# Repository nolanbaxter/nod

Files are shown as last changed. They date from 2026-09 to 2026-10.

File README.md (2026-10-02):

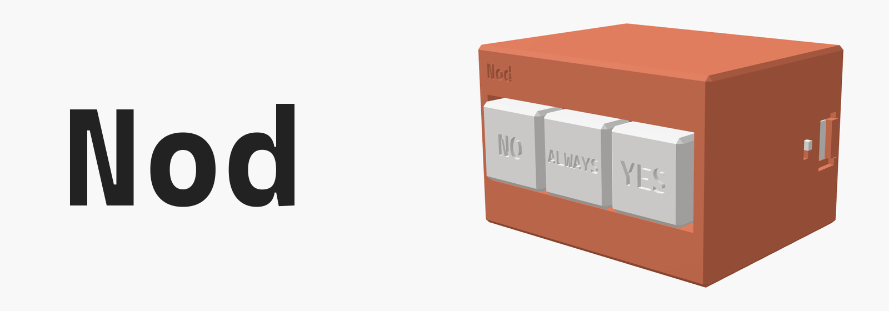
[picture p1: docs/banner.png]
Nod


A three-key desk pad for answering coding-agent permission prompts: **No**, **Always**, **Yes**.
Built for [Claude Code](https://docs.anthropic.com/en/docs/claude-code)'s numbered prompts, but
the keys are one line to remap. Works over USB-C or Bluetooth, runs on a small LiPo, and sleeps
when you're not using it.

> **Status:** built and working. The first one is the [Clawd variant](#clawd-variant), tested on
> real hardware over USB and Bluetooth in both the desktop app and the terminal. The plain Nod
> box shares its plate, keycaps and insides, but its current body and lid haven't been printed yet.

Not affiliated with or endorsed by Anthropic.

## Keys

| Key (left to right) | Sends | In a Claude desktop app prompt |
|---|---|---|
| NO | `Esc` | Deny |
| ALWAYS | `Ctrl+Shift+Enter` | Always allow |
| YES | `Ctrl+Enter` | Allow once |

These are the shortcuts the Claude desktop app shows on its prompt buttons, tested on the real
device. The number keys shown next to the buttons are positional and change from prompt to prompt,
so Nod doesn't use them. Leave the cursor in the message box, not on the prompt card.

Some prompts (multi-step or piped commands) have only Deny and Allow once. There, ALWAYS does
nothing and YES allows once. Text you've typed in the message box isn't sent when YES approves a
prompt.

### Terminal keymap

Claude Code in a terminal numbers its options instead: 1 Yes, 2 don't ask again, 3 No (Yes/No
prompts have only 1 and 2). **Hold NO + ALWAYS for 3 s** to switch between the desktop and
terminal keymaps. The LED gives one long blink for desktop, two for terminal, and Nod remembers the
choice through sleep and power-off.

| Key | Sends | 3-option prompt | Yes/No prompt |
|---|---|---|---|
| NO | `Esc` | No | No |
| ALWAYS | `2` | Yes, don't ask again | No |
| YES | `1` | Yes | Yes |

Every key fires once, 80 ms after it's pressed (the wait tells a single press from a two-key hold). To remap, edit `CODE` (both keymaps) in [`src/main.cpp`](src/main.cpp) and the
`labels` in [`cad/case.scad`](cad/case.scad).

## How it behaves

- **USB or Bluetooth, automatically.** Plugged into a computer, it's a USB keyboard. Unplugged,
  or on a charger, it's a Bluetooth keyboard named **Nod**. Each press goes out one way only.
- **Sleep.** On battery, it deep-sleeps after 2 minutes without a press. Any key wakes it; that
  press is sent once Bluetooth reconnects (1â€“3 s), or dropped if that takes over 5 s, so a stale
  "Yes" never lands on a newer prompt.
- **Pairing.** It's discoverable as **Nod** whenever nothing is connected. To move it to another
  computer, hold **NO + YES** together for 3 s: it forgets every paired computer and waits for a
  new one. Remove Nod from the old computer's Bluetooth list too, or it keeps trying to reconnect.
  (Keys pressed together never send, so this can't approve a prompt by accident.)
- **LED** (the programmable one, next to the USB port):
  - quick flash: a key was sent
  - fast blink: pairing
  - short blink every second: waiting for a connection
  - short blink every 4 s: battery low (needs two resistors; see `BAT_PIN` in `src/main.cpp`)
- **Charging.** The XIAO's own red LED is on while the battery charges and goes out when it's full.
  The power switch has to be on.
- **Power switch** on the side cuts the battery. It has to be **on** for the battery to charge.

## Parts (one build)

| Part | Notes |
|---|---|
| Seeed Studio XIAO ESP32-S3 | The plain one, not Sense or Plus |
| 2.4 GHz FPC antenna, U.FL / IPEX-1 | The XIAO has no onboard antenna. ~50 Ã— 14 mm fits the case |
| 3 Ã— MX-style switches | 3-pin or 5-pin, plate-mount. Any feel |
| 502030 LiPo, 3.7 V ~250 mAh, **with protection circuit** | Stands on edge inside |
| SS12D00**G3** mini slide switch | Power. G3 = 3 mm slider; the case has a finger pocket sized for it. Not SS12D10/SS12F44 "5 mm knob" parts: their bodies are bigger |
| 8 Ã— 6 Ã— 2 mm disc magnets | Hold the lid on |
| 28â€“30 AWG silicone wire, heat-shrink, Kapton tape, gel superglue | |
| PLA | Case, plate, keycaps; a second colour for labels is optional |

## Wiring

Wiring diagram

Keys go to **D0 / D1 / D3** (NO / ALWAYS / YES), their other pins all to **GND**. No resistors:
the firmware uses the chip's internal pull-ups. The power switch sits in the battery's **+**
lead. Solder the battery last.

## Case

Parametric [OpenSCAD](https://openscad.org) model: [`cad/case.scad`](cad/case.scad).
Ready-to-print STLs are in `cad/stl/bevel/` (1 mm 45Â° edges) and `cad/stl/square/`.

| File | Print orientation |
|---|---|
| `body.stl` | As exported: top face down. Designed to print without supports (not yet test-printed) |
| `lid.stl` | Flat side down |
| `plate.stl` | Flat. Print this first to test how your switches clip in |
| `keycaps.stl` | Top face down. Labels are engraved; to fill them in a second colour, load `labels.stl` with it as one object |

The switch plate is a separate part so it prints perfectly flat; it drops into the key well and
gets a dab of glue. Glue the magnets in pairs: stack each pair first and mark the touching faces,
so the lid attracts instead of repelling.

Keycap labels use [Cascadia Code](https://github.com/microsoft/cascadia-code) Bold (free). The STLs
already have it baked in; to re-export them, install the font first, or OpenSCAD silently swaps in
a default one.

Useful knobs at the top of `case.scad`: `sw_hole` (switch fit), `cross_l`/`cross_w` (keycap fit),
`cap_proud` (how far keys stick out), `chamfer` (0 for square edges), and every `measure` value.

After changing anything, run the collision check (Windows, needs OpenSCAD and `pip install trimesh`):

```powershell
powershell -File cad/check.ps1
```

The README images are rendered from the model too: `powershell -File docs/banner/make_banner.ps1`
(add `-Target clawd` for the Clawd image; also needs `pip install pillow` and Microsoft Edge).

## Clawd variant

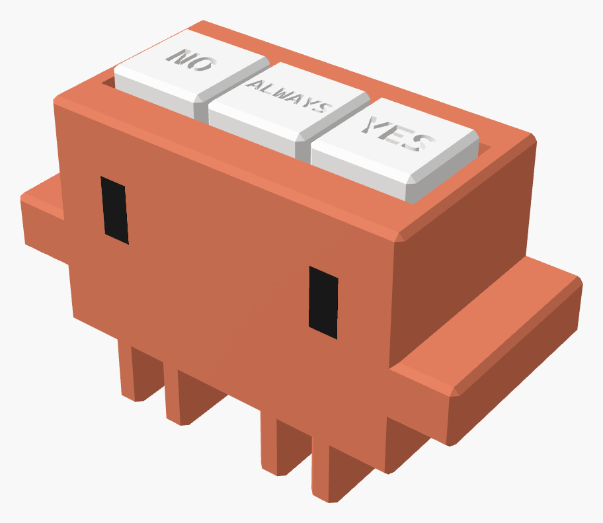
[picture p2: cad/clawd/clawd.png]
Clawd


*Unofficial, noncommercial fan-made recreation of Clawd, the Claude Code mascot. Not affiliated with, authorized, or endorsed by Anthropic.*

The same insides and keys in a Clawd-shaped body: [`cad/clawd/clawd.scad`](cad/clawd/clawd.scad)
builds on `case.scad`. The USB port, LED holes and power switch sit on the back wall, beside
each other. STLs are in `cad/clawd/stl/`; the plate and keycaps are the same as Nod's.

| File | Print orientation |
|---|---|
| `body.stl` + `eyes.stl` | As exported: top face down. Load together for black eyes. Supports under the arms |
| `lid.stl` | Standing on its legs. Supports under the plate between the legs |

The Clawd files are licensed **CC BY-NC 4.0** (noncommercial); see [`cad/clawd/LICENSE`](cad/clawd/LICENSE).

## Firmware

[PlatformIO](https://platformio.org), Arduino framework, NimBLE.

```bash
pio test -e native     # logic tests on your PC (needs gcc)
pio run -e xiao -t upload
```

If upload can't find the board, hold **BOOT** while plugging it in, then upload again.

| File | What |
|---|---|
| `src/main.cpp` | Pins, keymap, main loop, sleep |
| `src/usb_out.cpp`, `src/ble_out.cpp` | USB and Bluetooth keyboards (separate files: their headers clash) |
| `include/keys.h` | Debounce, wake-key and sleep decisions: pure logic, unit tested |

## License

Nod (firmware, case, docs): [MIT](LICENSE).
The Clawd variant in `cad/clawd/`: [CC BY-NC 4.0](cad/clawd/LICENSE), noncommercial use only.

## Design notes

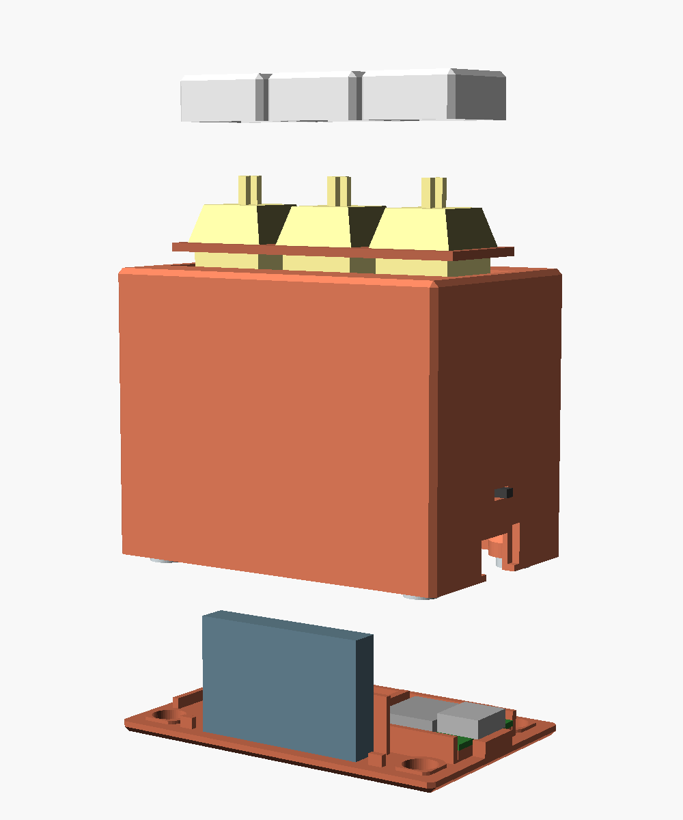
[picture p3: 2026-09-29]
cad/preview/exploded.png

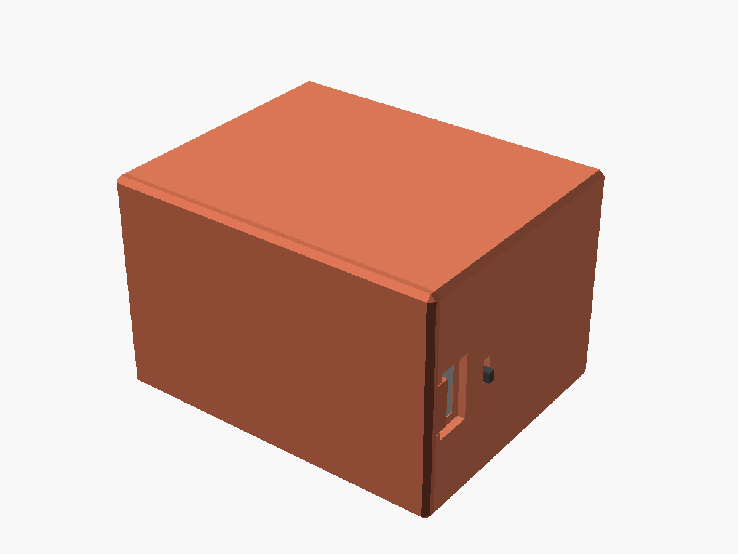
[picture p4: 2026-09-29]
cad/preview/lying.png

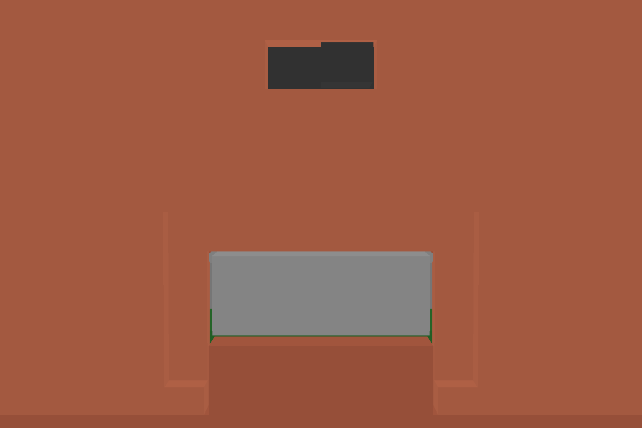
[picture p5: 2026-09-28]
cad/preview/port_closeup.png

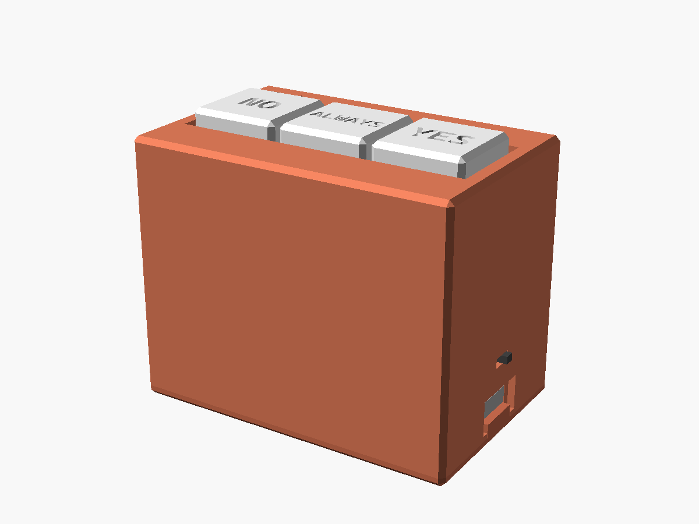
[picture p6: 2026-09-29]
cad/preview/upright.png

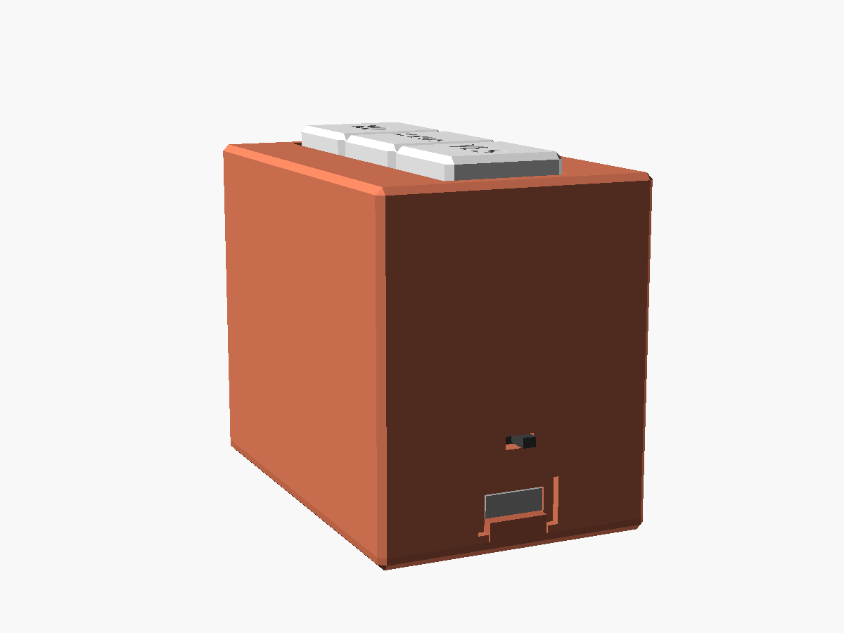
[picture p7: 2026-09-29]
cad/preview/port_side.png

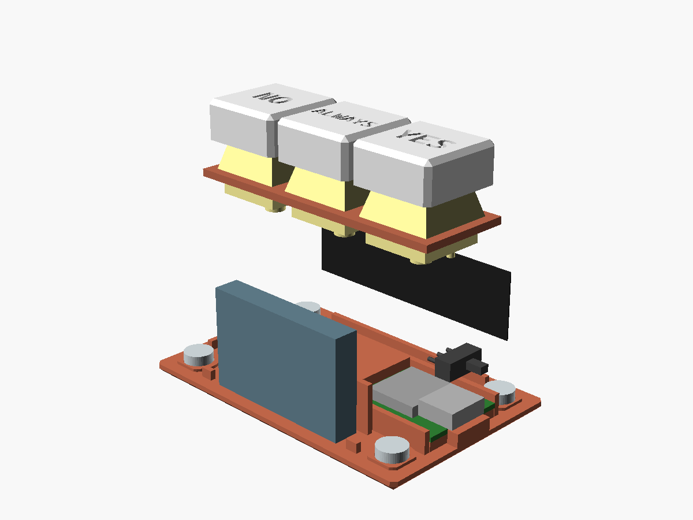
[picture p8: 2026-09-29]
cad/preview/inside.png

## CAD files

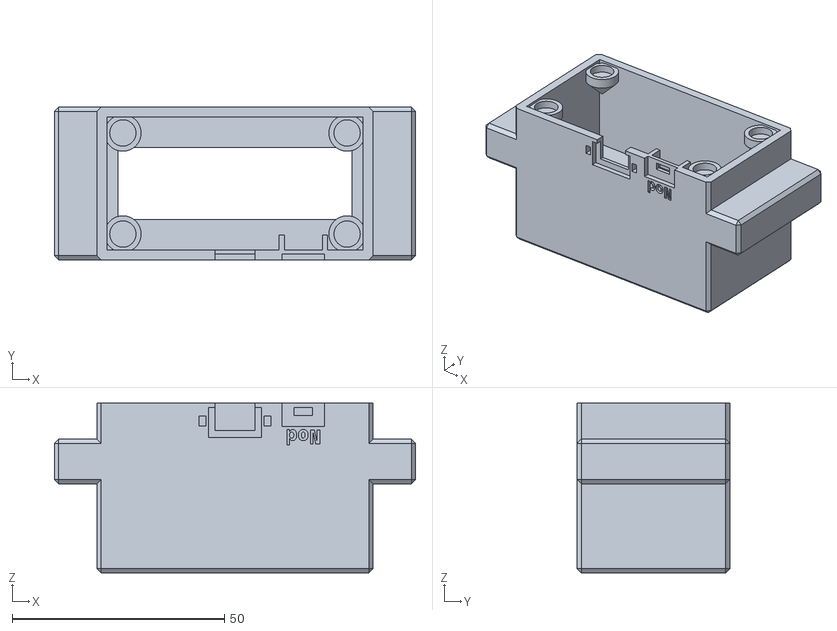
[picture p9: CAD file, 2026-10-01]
cad/clawd/stl/bevel/body.stl
85.0 x 36.0 x 40.0

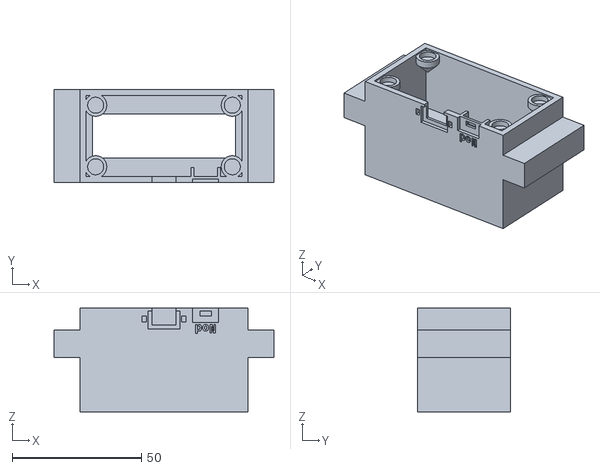
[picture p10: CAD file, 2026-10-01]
cad/clawd/stl/square/body.stl
85.0 x 36.0 x 40.0

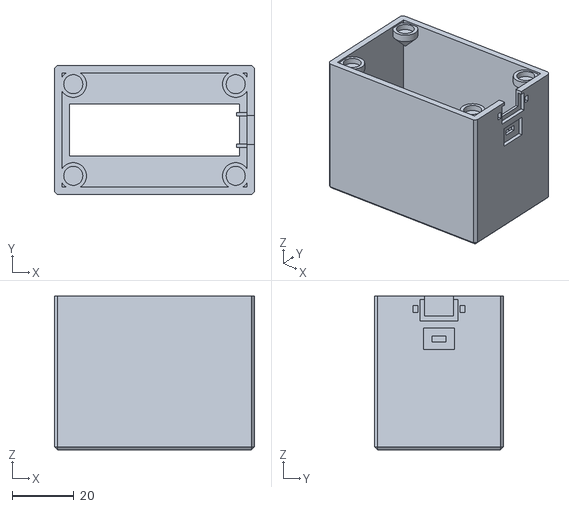
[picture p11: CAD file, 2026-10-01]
cad/stl/bevel/body.stl
65.0 x 42.0 x 50.0

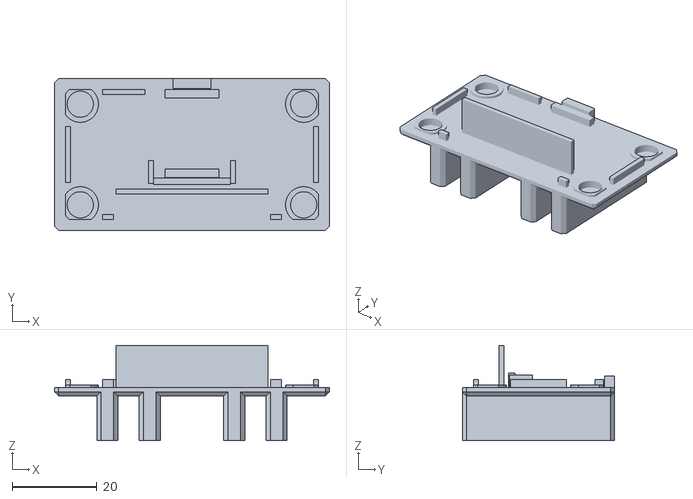
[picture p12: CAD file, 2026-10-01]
cad/clawd/stl/bevel/lid.stl
65.0 x 36.0 x 22.5

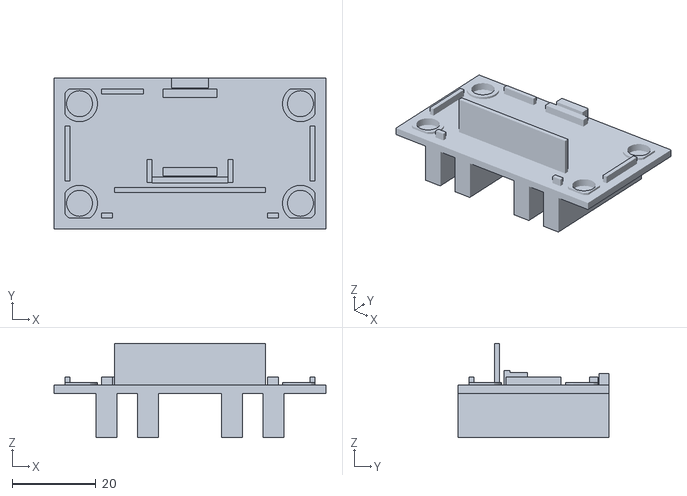
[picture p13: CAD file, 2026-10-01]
cad/clawd/stl/square/lid.stl
65.0 x 36.0 x 22.5

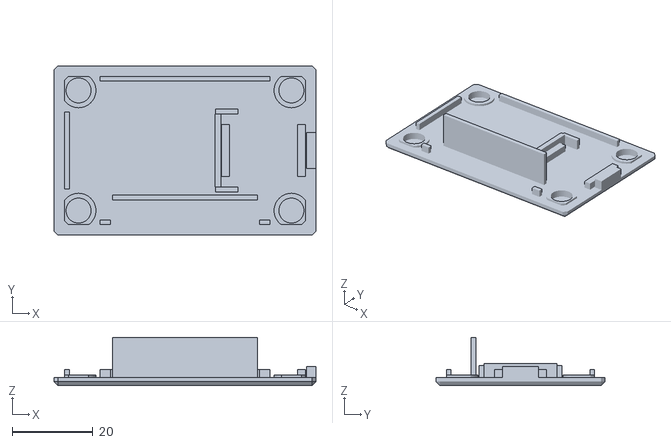
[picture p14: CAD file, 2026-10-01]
cad/stl/bevel/lid.stl
65.0 x 42.0 x 12.0

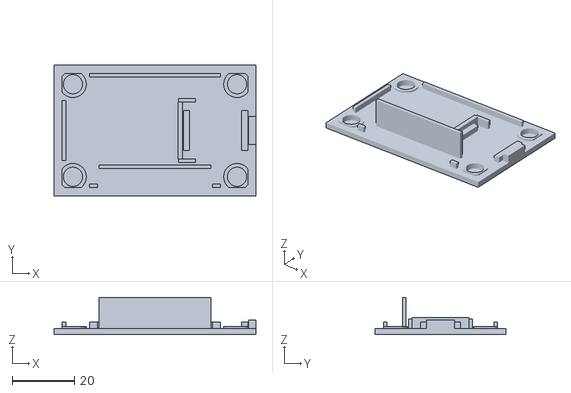
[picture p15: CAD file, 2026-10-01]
cad/stl/square/lid.stl
65.0 x 42.0 x 12.0

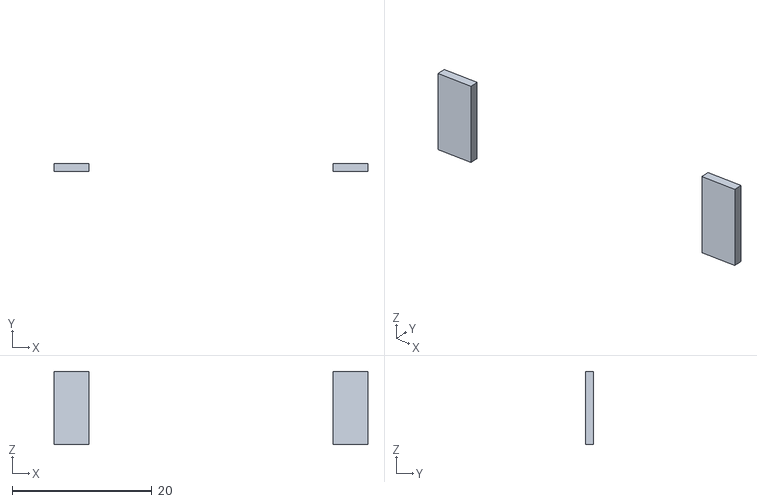
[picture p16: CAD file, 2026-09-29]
cad/clawd/stl/bevel/eyes.stl
45.0 x 1.21 x 10.5

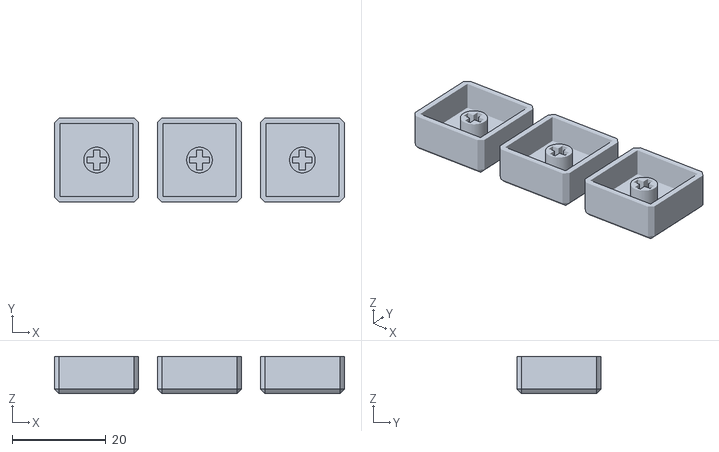
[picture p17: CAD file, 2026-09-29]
cad/stl/bevel/keycaps.stl
62.0 x 18.0 x 8.00

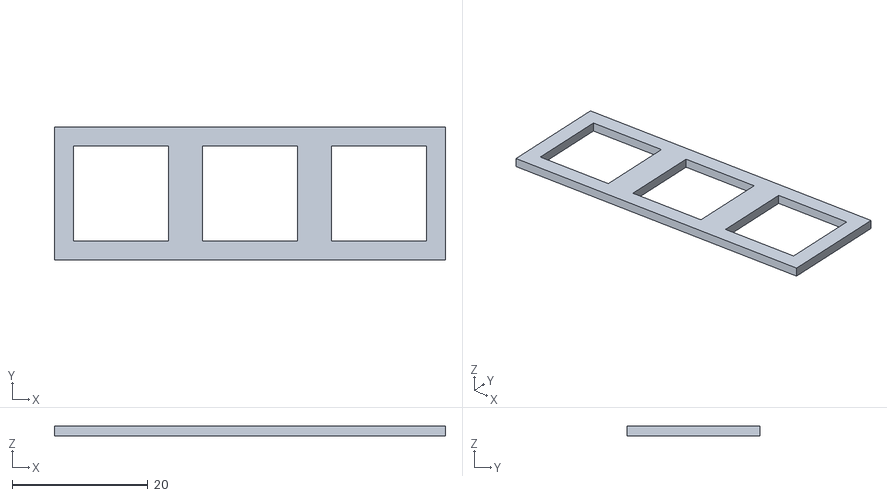
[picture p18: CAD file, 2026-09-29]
cad/stl/square/plate.stl
57.7 x 19.6 x 1.50

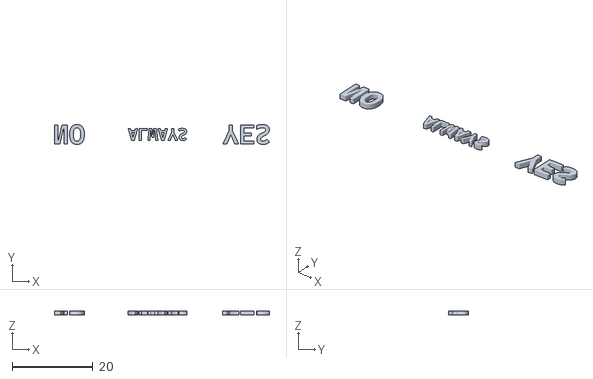
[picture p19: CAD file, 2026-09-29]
cad/stl/square/labels.stl
53.2 x 4.95 x 1.01

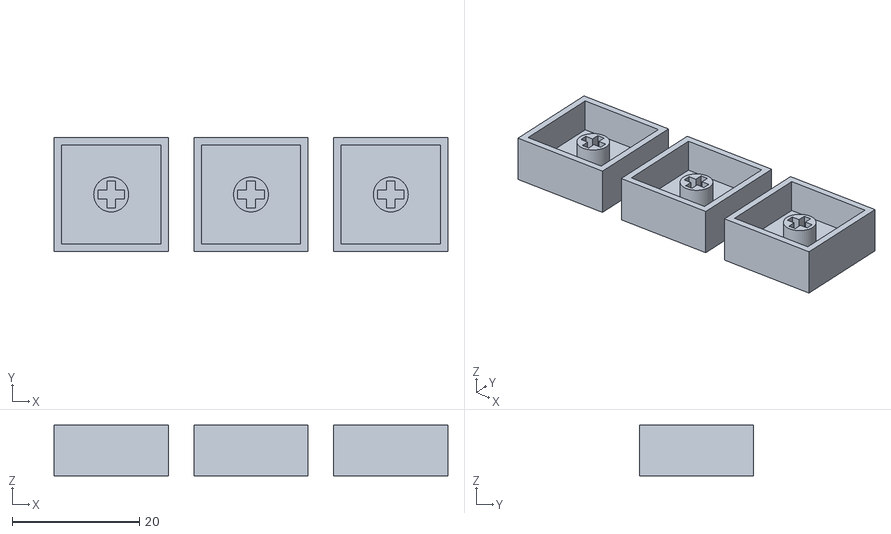
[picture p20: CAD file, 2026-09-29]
cad/stl/square/keycaps.stl
62.0 x 18.0 x 8.00

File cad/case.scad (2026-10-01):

// Nod case: a three-key box. Units mm.
// Coordinates: x centered, y=0 front face, y=depth back face, z=0 bottom of lid.
// Every "measure" value is a nominal guess until the real part is in hand.

part = "all"; // [all, body, lid, plate, keycaps, labels]

/* [Shape] */
W = 65;               // width; must fit 3 keys at 19.05 mm pitch
depth = 42;           // deep enough for the side USB port to fit between the corner magnets
H = 52;
wall = 2.4;
plate = 1.5;          // MX plate-mount thickness
lid_t = 2;
chamfer = 1;          // 45° bevel on outside edges; 0 = square; keep <= lid_t/2

/* [Switches] */
pitch = 19.05;
sw_hole = 14.0;       // tune +0.1 if switches won't clip in
cap_proud = 3;        // how far keycap tops stick out above the top face
well_gap = 1;         // gap around each keycap inside the key well
ledge = 1.5;          // lip the separate plate rests on
rim = 2;              // thickness of that lip

/* [XIAO ESP32-S3] measure */
xiao_l = 21;          // USB end against the right wall
xiao_w = 17.8;
pcb_t = 1.0;
xiao_lift = 2;        // clearance under board for battery-pad wires
usb_w = 8.94;         // receptacle
usb_h = 3.26;
usb_over = 1.0;       // how far the receptacle sticks past the PCB edge
usb_zc = 2.6;         // receptacle center above PCB bottom
plug_w = 12.5;        // cable overmold
plug_h = 7;

/* [Battery] 502030 LiPo, listed 20.5 x 32 x 5.3 */
bat_l = 32;
bat_t = 5.3;
bat_slack = 1;        // LiPos swell

/* [Power switch] SS12D00-G3 mini slide switch (3 mm slider), measure */
sw_l = 8.6;           // body length (slide direction)
sw_w = 3.6;
sw_h = 3.5;
knob_l = 2.0;         // slider cross-section
knob_w = 1.5;
knob_travel = 2.0;
knob_h = 3;           // slider length past the switch face: G3 = 3 mm
sw_pocket = [10, 7];  // finger pocket around the slot on the outside (along the wall, height)
sw_pocket_wall = 1.0; // wall left at the pocket floor, so the 3 mm slider stands 2 mm proud

/* [Magnets] 6 x 2 mm discs */
mag_d = 6;            // diameter
mag_h = 2;            // thickness
mag_fit = 0.2;        // pocket clearance on diameter; glue them in
lip_h = 2;            // lid lip inside the walls: magnets hold vertically, the lip stops sliding

/* [Antenna] 2.4 GHz FPC, U.FL/IPEX-1, 50 x 14 */
ant_l = 50;
ant_w = 14;
ant_z = 12.2;         // bottom edge height on the back wall

/* [Keycaps] */
cap = 18;
cap_wall = 1.2;
cap_top = 2.4;
cap_skirt = 5.6;      // skirt bottom to socket bottom
cap_rest = 6.0;       // skirt bottom height above the plate at rest (MX stem top is 11.6 above plate)
stem_d = 5.5;
cross_l = 4.2;        // tune for stem fit
cross_w = 1.35;
cross_depth = 4;
labels = ["NO", "ALWAYS", "YES"];   // left to right, matches src/main.cpp CODE[]
label_size = [5, 3.1, 5];
label_font = "Cascadia Code:style=Bold";   // free, github.com/microsoft/cascadia-code; OpenSCAD silently falls back if missing
label_depth = 1.0;   // engraving depth for key labels and the logo

/* [Logo] engraved on the top face, behind the keys */
logo = "Nod";
logo_size = 3.5;
logo_side = "left";   // [left, right]

/* [Fit] */
tol = 0.2;

$fn = 48;
cap_h = cap_skirt + cap_top;
port_z = lid_t + xiao_lift + usb_zc;          // USB center height
cav = [W - 2*wall, depth - 2*wall];           // interior footprint
mag_pd = mag_d + mag_fit;                     // pocket diameter
boss_d = mag_pd + 2.4;
mag_off = mag_pd/2 + tol + 0.4;               // magnet center from inner wall faces
mag_z = max(lid_t, mag_h + 0.6);              // where magnet faces meet
boss_top = mag_z + mag_h + 0.6 + boss_d/2;    // tip of the 45° cone above each body boss
mag_xy = [for (sx = [-1, 1], y = [wall + mag_off, depth - wall - mag_off])
          [sx * (W/2 - wall - mag_off), y]];
led_z0 = port_z + plug_h/2 + 0.5;             // clear band above the plug recess (Nod's switch and the antenna sit above it)
led_top = led_z0 + 1.5;
// The XIAO's two LEDs sit either side of the USB-C, ~40% of the way from the port edge to the board edge
// (measured on the real board). Their holes go just outside the plug recess so a plugged-in cable
// doesn't cover the charge LED.
led_hole = [1.6, 2.4];                         // width, height; bottom at the board's top face
led_hole_x = plug_w/2 + 0.6 + led_hole.x/2;    // centre, either side of the port
well = [2*pitch + cap + 2*well_gap, cap + 2*well_gap];   // key well footprint, centered on the top
plate_top = H - (cap_rest + cap_h - cap_proud);          // switch plate sits at the bottom of the well
ceil_z = plate_top - plate - rim;                        // underside of the solid top block

// Port cluster (USB, LED holes, power switch, XIAO pocket), modelled in a local frame:
// x along the wall, y = 0 at its outer face and negative going inside.
// Nod: right side wall, switch above the port (that wall is too short for both side by side).
xl0 = -wall - xiao_l;                          // PCB inner edge; the USB edge butts the wall
port_side = "right";                           // right | back
sw_lx = 0;                                     // power switch position along the port wall
sw_z = led_top + 2 + sw_w/2;
rib_z0 = sw_z - sw_w/2 - 1;                    // bottom of the switch guide ribs
module at_port() {
  if (port_side == "back") translate([0, depth, 0]) children();
  else translate([W/2, depth/2, 0]) rotate(-90) children();
}

// Hooks for variants built on this file (see cad/clawd/clawd.scad); empty for Nod.
lid_lift = 0;                                  // raise the exported lid (e.g. for legs)
module body_add() {}
module body_cut() {}
module lid_add() {}
module preview_add() {}

assert(port_z - plug_h/2 > lid_t, "cable overmold would hit the lid; raise xiao_lift");
assert(ant_z > led_top && ant_z + ant_w + 1 < ceil_z, "antenna overlaps the band above the port or the top block; move ant_z");
assert(well.x + 2 < W, "key well too wide for the body");
assert(ant_l + 1 < cav.x && (ant_z > boss_top || ant_l/2 + 0.5 < cav.x/2 - mag_off - boss_d/2),
       "antenna runs into a corner magnet boss");
assert(2*chamfer <= lid_t && 2*chamfer <= wall, "chamfer too big for lid/wall");

module box(p, s) translate(p) cube(s);

// box with 45° chamfers on all edges; bot/top=false leaves that face's edges square
module cbox(p, s, bot = true, top = true, c = chamfer) {
  lo = bot ? 0 : c;
  h = s.z + lo + (top ? 0 : c);
  intersection() {
    box(p, s);
    translate(p - [0, 0, lo]) hull() {
      translate([c, c, 0]) cube([s.x - 2*c, s.y - 2*c, h]);
      translate([c, 0, c]) cube([s.x - 2*c, s.y, h - 2*c]);
      translate([0, c, c]) cube([s.x, s.y - 2*c, h - 2*c]);
    }
  }
}

// logo sits in the strip between the key well and the back edge, flush with the well's left or right edge
module logo_shape() {
  right = logo_side == "right";
  translate([right ? well.x/2 : -well.x/2, depth - (depth/2 - well.y/2)/2, H - label_depth])
    linear_extrude(label_depth + 0.01)
      text(logo, size = logo_size, halign = right ? "right" : "left", valign = "center", font = label_font);
}
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

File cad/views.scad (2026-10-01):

// Extra render views. Run with -D view="port" | "lying" | "banner" | "banner_body" | "banner_accent".
include <case.scad>
part = "none";
view = "port";

if (view == "port") {  // right side: USB port, LED holes, power switch
  color("#DA7756") body();
  color("#C86A4C") lid();
  xiao_dummy();
  slide_dummy();
}
if (view == "lying") rotate([-90, 0, 0]) assembly();  // on its back
if (view == "banner") rotate([90, 0, 0]) assembly();  // on its front: keys face the camera, labels read upright
// banner colour groups, exported as real geometry (the preview renderer mangles shallow engravings)
if (view == "banner_body") rotate([90, 0, 0]) { body(); lid(); }
if (view == "banner_accent") rotate([90, 0, 0]) { keycaps_placed(); slide_dummy(); xiao_dummy(); }

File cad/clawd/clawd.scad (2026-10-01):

// Clawd style of the Nod case: the pixel mascot, with the keys on its head.
// Unofficial, noncommercial fan work, licensed CC BY-NC 4.0 (see LICENSE in this folder).
// Everything inside (XIAO pocket, magnets, key well, keycaps) comes from ../case.scad;
// this file only changes the shape and moves the port cluster to the back wall.
include <../case.scad>

/* [Clawd] */
px_w = 5;             // one pixel of the sprite; 13 px wide = the Nod width
px_h = 10.5;          // px_w * 2.1: terminal half-block aspect
eye_d = 1.2;          // eye recess depth (fill with eyes.stl in black)
depth = 36;
H = 42;               // 4 px_h tall (+ 1 px_h of legs under the lid)
port_side = "back";
sw_lx = 16.1;         // power switch beside the port, sitting on the lid
sw_z = lid_t + tol + sw_w/2;
rib_z0 = lid_t;
lid_lift = 10.5;      // legs hang below the lid
logo = "";
sink = max(2*chamfer, 0.5);   // arms/legs overlap the body so their bevels are buried

module eyes() for (c = [2, 10]) box([-W/2 + c*px_w, -0.01, 2*px_h], [px_w, eye_d + 0.01, px_h]);
module body_add() for (s = [-1, 1]) cbox([s > 0 ? W/2 - sink : -W/2 - 2*px_w, 0, px_h], [2*px_w + sink, depth, px_h]);
// "Nod" engraved on the back wall above the power switch (the space above the port is kept clear).
// rotate: text stands up on the back face and reads correctly from behind; it cuts label_depth in.
module back_logo() translate([sw_lx, depth - label_depth, sw_z + sw_pocket.y/2 + 2.5]) rotate([90, 0, 180])
  linear_extrude(label_depth + 0.01) text("Nod", size = logo_size, halign = "center", valign = "center", font = label_font);
module body_cut() { eyes(); back_logo(); }
module lid_add() for (c = [2, 4, 8, 10]) cbox([-W/2 + c*px_w, 0, -px_h], [px_w, depth, px_h + sink], bot = false);
module preview_add() color("black") eyes();

if (part == "eyes") flip(H) eyes();

// colour groups for the README render (docs/banner/make_banner.ps1 -Target clawd)
if (part == "img_body") { body(); lid(); }
if (part == "img_eyes") eyes();
if (part == "img_accent") { keycaps_placed(); slide_dummy(); xiao_dummy(); }

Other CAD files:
cad/stl/square/body.stl
cad/stl/bevel/plate.stl

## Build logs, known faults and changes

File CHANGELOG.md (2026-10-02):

# Changelog

All notable changes to this project are documented here.
Format: [Keep a Changelog](https://keepachangelog.com/en/1.1.0/), versioning: [SemVer](https://semver.org/).

## [Unreleased]

### Added
- Firmware for the Seeed XIAO ESP32-S3: three keys with two keymaps, switched by holding NO + ALWAYS: the Claude desktop app's prompt shortcuts (Esc / Ctrl+Shift+Enter / Ctrl+Enter) and the terminal's (Esc / 2 / 1), USB keyboard when a computer is
  attached, Bluetooth LE keyboard otherwise, deep sleep after 2 minutes idle on battery, wake key
  delivered once Bluetooth reconnects. Unit tests for the key, wake, and sleep logic.
- Parametric OpenSCAD case with a key well, separate switch plate, magnet-held lid, side USB-C
  port, power switch (SS12D00-G3, in a finger pocket), and LED holes beside the port; bevelled and square STLs; a collision check against
  stand-ins for every bought part.
- LED flashes on every key press; hold NO + YES for 3 s to forget paired computers and pair a new
  one (keys pressed together never send); optional low-battery blink with a two-resistor divider.
- Wiring diagram.
- Clawd variant (`cad/clawd/`, CC BY-NC 4.0): the same case internals in a body shaped like the
  Claude Code mascot, with the port cluster on the back wall. Unofficial fan work.
- `make_banner.ps1 -Target nod|clawd` renders the README images from the model.

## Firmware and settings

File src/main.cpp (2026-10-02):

#include <Arduino.h>
#include <driver/rtc_io.h>
#include <esp_sleep.h>
#include <Preferences.h>
#include "keys.h"

// usb_out.cpp / ble_out.cpp
void usbBegin(); bool usbUp(); void usbSend(const uint8_t *keys, int n);
void bleBegin(); bool bleUp(); void bleSend(const uint8_t *keys, int n); void blePair();

// Switch leg -> GPIO, other leg -> GND. All RTC-capable so any key wakes from deep sleep; D2 (GPIO3, strapping) skipped.
// Power is a slide switch in the battery lead.
constexpr uint8_t PIN[3] = {1, 2, 4};              // D0, D1, D3
// Left to right: No, Always, Yes. Each row is pressed together; 0 = unused. Key codes are the same in both
// keyboard libraries: 0x80 Ctrl, 0x81 Shift, 0xB0 Enter, 0xB1 Esc. Hold NO + ALWAYS 3 s to switch keymaps.
constexpr uint8_t CODE[2][3][3] = {
  // 0, desktop app: the shortcuts shown on its prompt buttons (its number keys are positional, so not used)
  {{0xB1}, {0x80, 0x81, 0xB0}, {0x80, 0xB0}},
  // 1, terminal CLI: options are 1 Yes, 2 don't-ask-again, 3 No; Yes/No prompts have only 1 and 2,
  // so No is Esc (works on both) and '2' on a Yes/No prompt errs safe (No)
  {{0xB1}, {'2'}, {'1'}},
};
constexpr int LED = 21;                            // XIAO user LED, active low
// Battery sense: the XIAO can't read its battery by itself. Fit two equal resistors (100k-220k):
// BAT+ -> R -> D4 -> R -> GND, then set this to 5 (D4 = GPIO5). -1 = not fitted, no low-battery warning.
constexpr int BAT_PIN = -1;
constexpr uint32_t BAT_LOW_MV = 3500;              // roughly the last 10-15% of a LiPo
constexpr uint32_t PAIR_MAX_MS = 120000;           // pairing blink gives up after this

Keys keys;
Chord chord;
Pending pending;
uint32_t lastActive, flashAt, pairAt, batAt, mapAt;
uint8_t keymap;                                    // index into CODE, saved in flash
Preferences prefs;
uint8_t pairing;                                   // 0 off, 1 waiting for the old link to drop, 2 waiting for a new one
bool batLow;

bool readBatLow() {
  if (BAT_PIN < 0) return false;
  uint32_t mv = 0;
  for (int i = 0; i < 16; i++) mv += analogReadMilliVolts(BAT_PIN);
  return mv / 16 * 2 < BAT_LOW_MV;
}

uint8_t readKeys() {
  uint8_t m = 0;
  for (int i = 0; i < 3; i++) if (!digitalRead(PIN[i])) m |= 1 << i;
  return m;
}

// USB when a computer is on the cable, otherwise Bluetooth. Dropped if neither is connected.
void send(const uint8_t *code) {
  int n = 0;
  while (n < 3 && code[n]) n++;
  if (usbUp()) usbSend(code, n);
  else if (bleUp()) bleSend(code, n);
}

void sleepNow() {
  digitalWrite(LED, HIGH);
  uint64_t mask = 0;
  for (auto p : PIN) {
    rtc_gpio_pullup_en((gpio_num_t)p);
    rtc_gpio_pulldown_dis((gpio_num_t)p);
    mask |= 1ULL << p;
  }
  esp_sleep_pd_config(ESP_PD_DOMAIN_RTC_PERIPH, ESP_PD_OPTION_ON);  // keep the pull-ups alive
  esp_sleep_enable_ext1_wakeup(mask, ESP_EXT1_WAKEUP_ANY_LOW);
  esp_deep_sleep_start();  // wakes as a fresh boot
}

void setup() {
  // ponytail: 80 MHz is plenty and saves power; if USB ever misbehaves, delete this line first
  setCpuFrequencyMhz(80);
  for (auto p : PIN) { rtc_gpio_deinit((gpio_num_t)p); pinMode(p, INPUT_PULLUP); }  // undo sleep's RTC mux
  pinMode(LED, OUTPUT);
  digitalWrite(LED, HIGH);

  if (esp_sleep_get_wakeup_cause() == ESP_SLEEP_WAKEUP_EXT1) {
    uint64_t st = esp_sleep_get_ext1_wakeup_status();
    uint8_t k = 0;
    for (int i = 0; i < 3; i++) if (st & (1ULL << PIN[i])) k |= 1 << i;
    pending.set(k, millis());
  }

  prefs.begin("nod");
  keymap = prefs.getUChar("keymap", 0) % 2;
  usbBegin();
  bleBegin();
  keys.begin(readKeys(), millis());  // the wake key is still held; Pending sends it, not Keys
  lastActive = millis();
}

void loop() {
  uint32_t now = millis();
  uint8_t held = readKeys();
  bool usb = usbUp(), ble = bleUp(), linked = usb || ble;

  uint8_t ev = chord.step(keys.step(held, now), keys.down, now);
  if (chord.chord) pending.keys = 0;                 // woke by a pairing hold: don't send the wake key
  ev |= pending.take(linked, now);
  for (int i = 0; i < 3; i++) if (ev & (1 << i)) { send(CODE[keymap][i]); flashAt = now; }
  if (ev & PAIR) { blePair(); pairing = 1; pairAt = now; }
  if (ev & MODE) { keymap ^= 1; prefs.putUChar("keymap", keymap); mapAt = now; }
  if (ev || held || usb) lastActive = now;

  if (pairing == 1 && !ble) pairing = 2;
  if ((pairing == 2 && ble) || now - pairAt > PAIR_MAX_MS) pairing = 0;
  if (now - batAt >= 10000) { batAt = now; batLow = readBatLow(); }

  bool on;
  if (pairing) on = now % 200 < 100;                 // fast blink: pairing
  else if (mapAt && now - mapAt < 1000)              // keymap switched: 1 long blink = desktop, 2 = terminal
    on = (now - mapAt) % 500 < 250 && (now - mapAt) / 500 <= keymap;
  else if (now - flashAt < 60) on = true;            // a key was just sent
  else if (!linked) on = now % 1000 < 30;            // short blink every second: waiting for a connection
  else on = batLow && now % 4000 < 30;               // short blink every 4 s: battery low
  digitalWrite(LED, !on);
  if (shouldSleep(now, lastActive, usb, held)) sleepNow();
  delay(2);
}

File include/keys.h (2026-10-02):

#pragma once
#include <stdint.h>

// Pure logic (no Arduino) so it runs in the native test.

constexpr uint32_t DEBOUNCE_MS = 10;          // tune if switches chatter
constexpr uint32_t IDLE_MS = 2 * 60 * 1000;   // on battery: deep sleep after this long without a press
constexpr uint32_t WAKE_SEND_MS = 5000;       // how long a wake press waits for BLE to reconnect

enum : uint8_t { K1 = 1, K2 = 2, K3 = 4 };

// Input: bitmask of keys physically down. Output: bitmask of keys newly pressed.
struct Keys {
  uint8_t raw = 0, down = 0;
  uint32_t rawAt = 0;

  // Keys already held at boot never send.
  void begin(uint8_t pressed, uint32_t now) { raw = down = pressed; rawAt = now; }

  uint8_t step(uint8_t pressed, uint32_t now) {
    if (pressed != raw) { raw = pressed; rawAt = now; }
    if (raw == down || now - rawAt < DEBOUNCE_MS) return 0;
    uint8_t pressedNow = raw & ~down;
    down = raw;
    return pressedNow;
  }
};

constexpr uint32_t CHORD_MS = 80;             // a press waits this long in case a second key joins it
constexpr uint32_t HOLD_MS = 3000;            // two-key holds: NO + YES = Bluetooth pairing, NO + ALWAYS = keymap
constexpr uint8_t PAIR = 0x80, MODE = 0x40;   // bits in Chord::step's result

// Sits after Keys: input is Keys' newly-pressed bits and its debounced held mask. Holds each press for
// CHORD_MS, so two keys pressed together send nothing (pairing must never leak an Enter or a '2').
// Output: keys to send, plus PAIR / MODE once NO + YES / NO + ALWAYS have been held HOLD_MS.
struct Chord {
  uint8_t wait = 0;
  uint32_t at = 0, chordAt = 0;
  bool chord = false, fired = false;

  uint8_t step(uint8_t pressed, uint8_t down, uint32_t now) {
    if (down & (down - 1)) {               // two or more held: a chord, never sends keys
      if (!chord) { chord = true; chordAt = now; wait = 0; }
      if (fired || now - chordAt < HOLD_MS) return 0;
      fired = true;
      if (down == (K1 | K3)) return PAIR;
      if (down == (K1 | K2)) return MODE;
      return 0;
    }
    if (chord) {                           // stays a chord until every key is up
      if (!down) chord = fired = false;
      return 0;
    }
    if (pressed) { if (!wait) at = now; wait |= pressed; }
    if (wait && now - at >= CHORD_MS) { uint8_t k = wait; wait = 0; return k; }
    return 0;
  }
};

// The key that woke the board from deep sleep: sent once a link is up, dropped if that takes too long
// (a stale "Yes" arriving late is worse than none).
struct Pending {
  uint8_t keys = 0;
  uint32_t since = 0;

  void set(uint8_t k, uint32_t now) { keys = k; since = now; }

  uint8_t take(bool linked, uint32_t now) {
    if (!keys) return 0;
    if (now - since > WAKE_SEND_MS) { keys = 0; return 0; }
    if (!linked) return 0;
    uint8_t k = keys;
    keys = 0;
    return k;
  }
};

// Never sleep on USB (it's powered) or with a key held (it would wake instantly).
inline bool shouldSleep(uint32_t now, uint32_t lastActive, bool usbUp, uint8_t held) {
  return !usbUp && !held && now - lastActive >= IDLE_MS;
}

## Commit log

2026-09-28 Nod: three-key USB/Bluetooth prompt pad
    Firmware (PlatformIO, XIAO ESP32-S3): three keys (Esc / 2 / 1), USB HID
    when a computer is attached, BLE (NimBLE) otherwise, deep sleep after
    5 min idle on battery with the wake key delivered once BLE reconnects.
    Native unit tests for the key, wake and sleep logic; CI runs them and
    the firmware build.
    Case (OpenSCAD): key well with separate switch plate, magnet lid, side
    USB-C port with LED window and power switch, bevelled and square STLs,
    and a collision check against stand-ins for every bought part.
    Wiring diagram, README, MIT license, changelog.
    [body.stl, case.scad, keycaps.stl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]
2026-09-29 Keys send Esc / 2 / Enter; README banner
    Tested live in the Claude desktop app: number keys pick buttons by position ('1' is Deny there but Yes in the terminal), while Esc, '2' and Enter mean No / Always / Yes in both. README notes the focu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
    [views.scad]
2026-09-29 Code-font engraved labels and logo; two-tone banner
    Keycap labels and a small 'Nod' logo behind the keys are engraved 1 mm in Cascadia Code Bold (fill with labels.stl for a second colour, or leave plain). Banner rendered from the real geometry in the 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
    [body.stl, case.scad, keycaps.stl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]
2026-09-29 Add Clawd variant (CC BY-NC 4.0) built on the shared case
    cad/clawd/clawd.scad includes case.scad and fills its new hooks (port side, switch position, body/lid add-ons) with Clawd's arms, legs, eyes and back-wall port. Engraved Cascadia Code keycaps are sha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
    [body.stl, case.scad, clawd.scad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]
2026-09-29 Clawd: engrave Nod on the back wall above the power switch
    [body.stl, clawd.scad]
2026-09-29 Finger pocket around the power switch slot
    The SS12D00G3 slider is 3 mm long, so through the full 2.4 mm wall it would stick out only 0.6 mm. A 10 x 7 mm pocket thins the wall to 1 mm around the slot so it stands 2 mm proud. Applies to Nod an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
    [body.stl, case.scad, clawd.scad]
2026-09-29 Name the SS12D00-G3 power switch; fix YES label in wiring diagram
    Parts list, wiring diagram and changelog name the exact switch (G3, 3 mm slider) and warn off the larger SS12D10/SS12F44 parts. The diagram still labelled YES as '1' from before the keymap change; it sends Enter.
    [case.scad]
2026-10-01 XIAO pocket: open sides for battery wires and the antenna cable
    Found on the first lid print: full-length side rails trapped the wires from the BAT+/BAT- pads under the board, and rails standing 1.5 mm above the board blocked the U.FL antenna cable. Side guides are now short blocks at each end, flush with the board's top face, leaving the middle of both sides open; the inner stop drops to 0.5 mm above the board.
    [case.scad, lid.stl]
2026-10-01 XIAO pocket: clear the edge-pad solder joints
    Wire-route review: the USB-end side guides sat 0.2 mm from the D0/5V/GND edge pads, so a solder fillet there would stop the board seating. That end is already centred by the receptacle in its wall notch, so those guides are gone; the inner-end guides stay. The two under-board ledges now stop 2.5 mm short of each edge so solder wicking under the pads can't rock the board.
    [case.scad, lid.stl]
2026-10-01 LED holes beside the USB port instead of a thin-wall window
    On the real board the two LEDs sit either side of the USB-C, about 40% of the way from the port edge to the board edge. Each gets a 1.6 x 2.4 mm hole through the wall, starting at the board's top face and placed just outside the plug recess so a plugged-in cable (charging) doesn't cover the charge LED. The rest of the layout keeps its spacing.
    [body.stl, case.scad, clawd.scad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]
2026-10-01 Key-press LED flash, NO+YES pairing hold, optional low-battery blink
    [body.3mf]
2026-10-01 Remove Bambu project file; ignore *.3mf
    [body.3mf]
2026-10-02 Keymap: the desktop app's prompt shortcuts (Esc, Ctrl+Shift+Enter, Ctrl+Enter)
    [main.cpp]
2026-10-02 Switchable keymaps: hold NO+ALWAYS to toggle desktop app / terminal (Esc, 2, 1)
